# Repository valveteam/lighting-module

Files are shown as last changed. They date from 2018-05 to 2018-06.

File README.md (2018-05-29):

# lighting-module

This repository holds the KiCad design files for the light sensor module of the valve, containing the following:

* Schematics for the light sensor module.
* PCB design files for the light sensor module.
* Gerber and drill files required for manufacture of the PCB.

Notes:

* The circuit and PCB designs for this module currently use the STR05S3V3 Switching Regulator for voltage regulation ([datasheet here](https://docs-emea.rs-online.com/webdocs/150c/0900766b8150c4bd.pdf)). Due to supply issues, we had to move the voltage regulation to a different component, the TR05S3V3 ([datasheet here](https://docs-emea.rs-online.com/webdocs/150c/0900766b8150c31a.pdf)) and we have moved this circuitry to the [control module](https://github.com/valveteam/control-module).

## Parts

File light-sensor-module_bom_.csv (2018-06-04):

Component | Description | Part | References | Value | Footprint | Quantity Per PCB | Datasheet
1 | Unpolarized capacitor | C | C2 C7 | 100nF | C_0805_HandSoldering | 2
2 | Unpolarized capacitor | C | C1 | 10uF | C_0805_HandSoldering | 1
3 | Unpolarized capacitor | C | C3 C4 C5 | 4.7uF | C_0805_HandSoldering | 3
4 |  | LED-RESCUE-light-sensor-module | D1 D2 D3 D4 | LED | LED_0805_HandSoldering | 4
5 |  | INDUCTOR | L1 | 3.3uH | WURTH_INDUCTOR | 1
6 |  | CONN_01X06 | P2 | HEADER_01X06 | Pin_Header_Straight_1x06_Pitch2.54mm | 1
7 |  | CONN_01X06 | P1 | MOLEX_01X06 | Molex_KK-6410-06_06x2.54mm_Straight | 1
8 |  | CONN_01X02 | P3 | TERM_01X02 | TE_TERM | 1
9 | Resistor | R | R1 | 10R | R_0805_HandSoldering | 1
10 | Resistor | R | R4 | 10k | R_0805_HandSoldering | 1
11 | Resistor | R | R5 | 1k | R_0805_HandSoldering | 1
12 | Resistor | R | R2 R3 | 4.7k | R_0805_HandSoldering | 2
13 | Resistor | R | R6 R7 R8 R9 | 470R | R_0805_HandSoldering | 4
14 |  | BH1750 | U3 | BH1750 | WSOF6 | 1
15 |  | STR05 | U1 | STR05 | STR05 | 1
16 |  | VEML6030 | U2 | VEML6030 | VEML6030 | 1
Component Groups: | 16
Component Count: | 26
Fitted Components: | 26
Number of PCBs: | 1
Total components: | 26
Schematic Version:
Schematic Date:
BoM Date: | 04/06/2018 09:53:13
Schematic Source: | C:/Users/tooyi/Dropbox/tfpb/lighting-module/light-sensor-module.sch
KiCad Version: | Eeschema 4.0.7

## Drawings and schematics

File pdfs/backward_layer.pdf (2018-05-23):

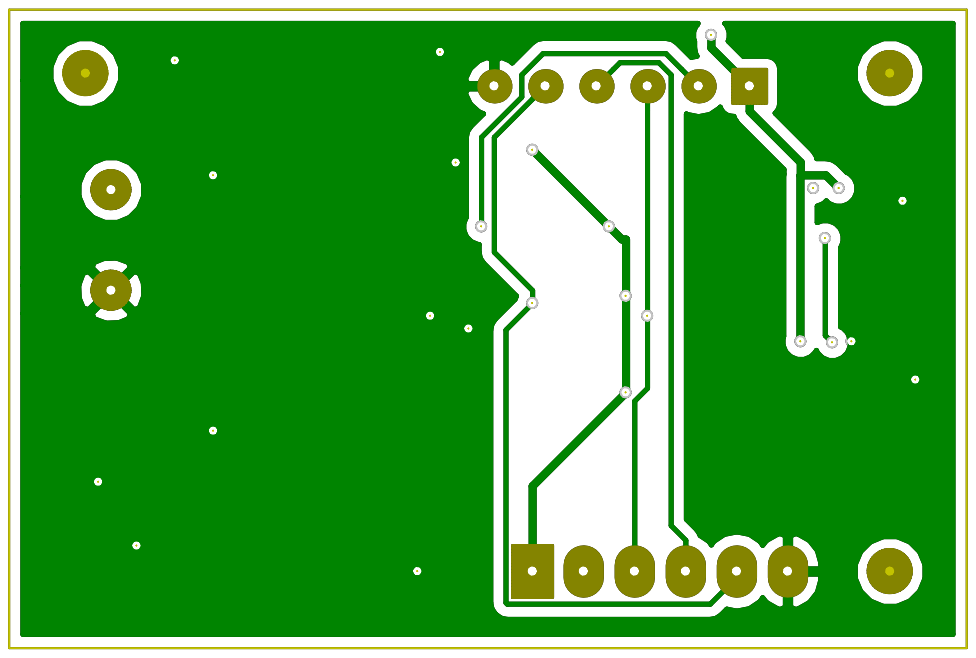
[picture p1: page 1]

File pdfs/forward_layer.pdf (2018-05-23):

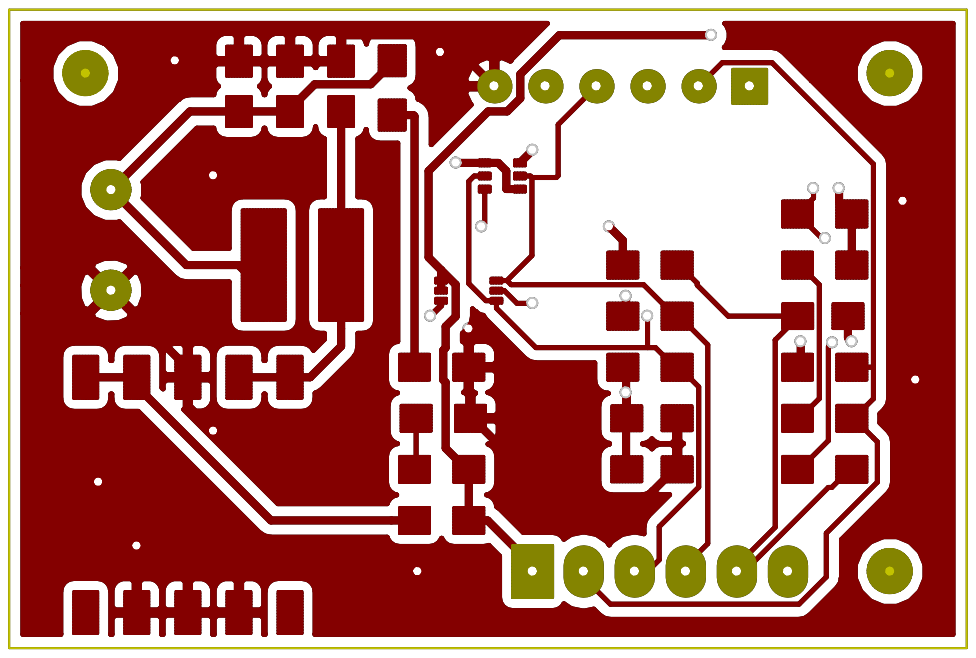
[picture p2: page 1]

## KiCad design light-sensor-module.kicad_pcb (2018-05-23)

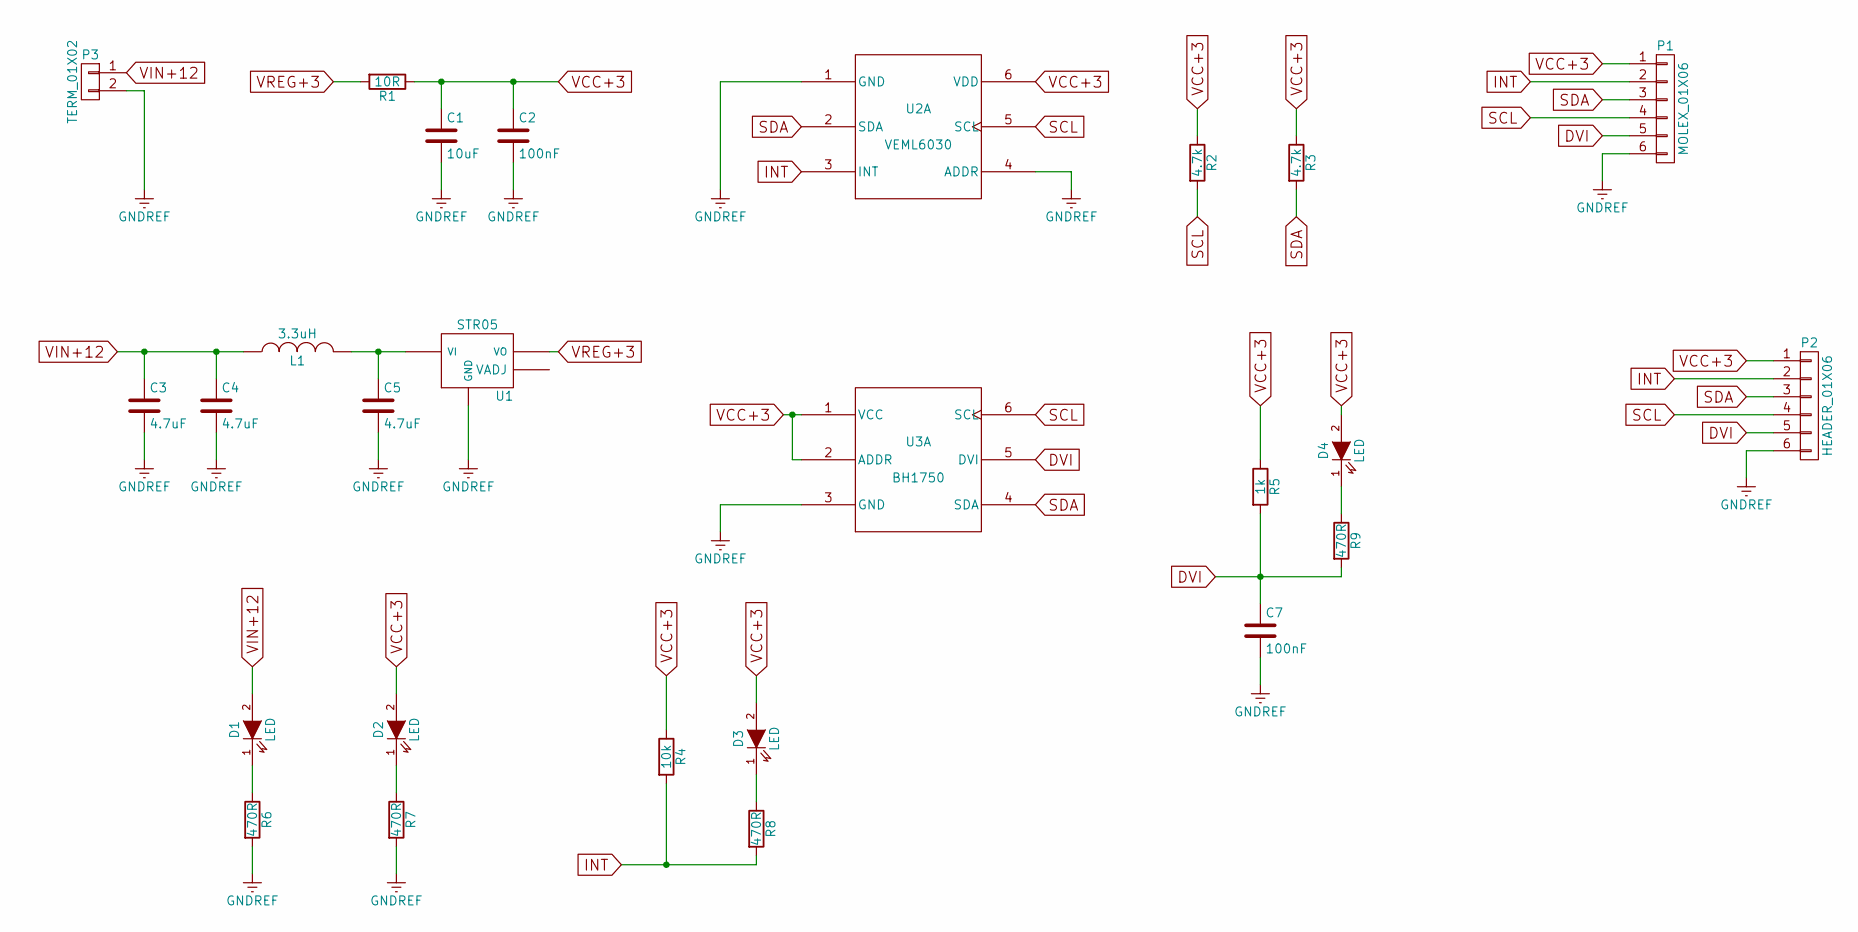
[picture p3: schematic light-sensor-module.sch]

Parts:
C1: 10uF; C_0805_HandSoldering
C2, C7: 100nF; C_0805_HandSoldering
C3, C4, C5: 4.7uF; C_0805_HandSoldering
D1, D2, D3, D4: LED; LED_0805_HandSoldering
L1: 3.3uH; WURTH_INDUCTOR
P1: MOLEX_01X06; Molex_KK-6410-06_06x2.54mm_Straight
P2: HEADER_01X06; Pin_Header_Straight_1x06_Pitch2.54mm
P3: TERM_01X02; TE_TERM
R1: 10R; R_0805_HandSoldering
R2, R3: 4.7k; R_0805_HandSoldering
R4: 10k; R_0805_HandSoldering
R5: 1k; R_0805_HandSoldering
R6, R7, R8, R9: 470R; R_0805_HandSoldering
U1: STR05
U2: VEML6030
U3: BH1750; WSOF6

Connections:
DVI: C7.1, P1.5, P2.5, R5.2, R9.2, U3.5 (DVI)
GNDREF: C1.2, C2.2, C3.2, C4.2, C5.2, C7.2, P1.6, P2.6, P3.2, R6.2, R7.2, U1.GND, U2.1 (GND), U2.4 (ADDR), U3.3 (GND)
INT: P1.2, P2.2, R4.2, R8.2, U2.3 (INT)
unnamed: C5.1, L1.2, U1.VI
unnamed: D1.1 (K), R6.1
unnamed: D2.1 (K), R7.1
unnamed: D3.1 (K), R8.1
unnamed: D4.1 (K), R9.1
SCL: P1.4, P2.4, R2.2, U2.5 (SCL), U3.6 (SCL)
SDA: P1.3, P2.3, R3.2, U2.2 (SDA), U3.4 (SDA)
VCC+3: C1.1, C2.1, D2.2 (A), D3.2 (A), D4.2 (A), P1.1, P2.1, R1.1, R2.1, R3.1, R4.1, R5.1, U2.6 (VDD), U3.1 (VCC), U3.2 (ADDR)
VIN+12: C3.1, C4.1, D1.2 (A), L1.1, P3.1
VREG+3: R1.2, U1.VO

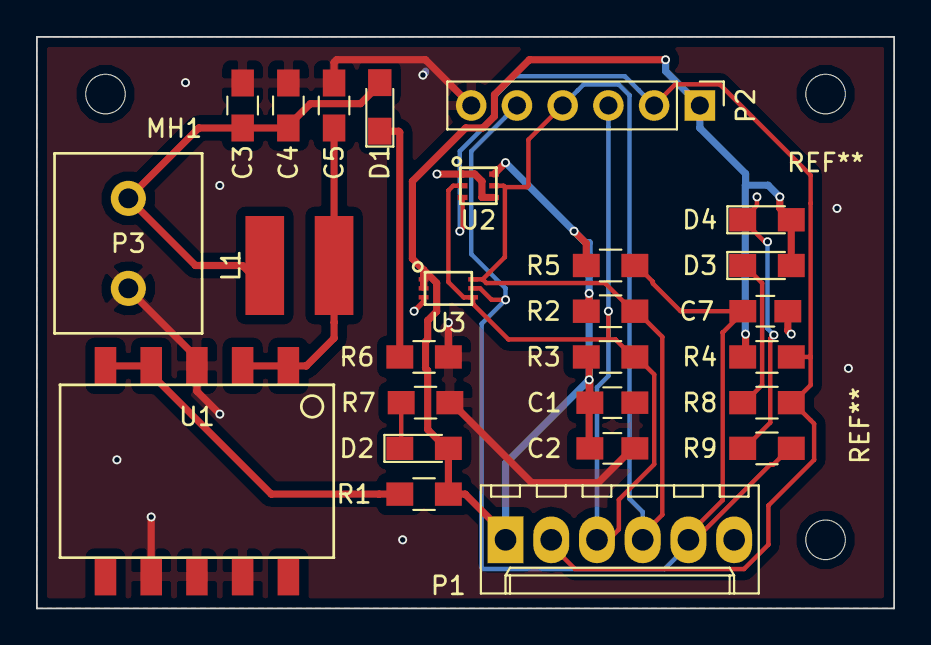
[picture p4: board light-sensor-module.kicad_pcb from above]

Board: 2 copper layers, 47.6 x 31.8 mm, 27 parts (0 on the bottom side), 13 nets.

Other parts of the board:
MH1: MountingHole_2.2mm_M2

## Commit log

2018-05-23 Complete PCB design
    [light-sensor-module.kicad_pcb, light-sensor-module.sch]
2018-05-23 Add Gerbers, PDFs and Drill File
    [light-sensor-module.kicad_pcb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]
